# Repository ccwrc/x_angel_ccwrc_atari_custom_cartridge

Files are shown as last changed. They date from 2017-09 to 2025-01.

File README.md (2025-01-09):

PCB look cartridge_pcb

## PCB fit to standard Atari XEGS (Taiwan), Warner and Sikor_Soft cases 

Details, manual, cookbook: [AtariOnline (Polish)](http://atarionline.pl/forum/comments.php?DiscussionID=4245&page=1#Item_0)      
Or auto translated to English: [AtariOnline (English - auto-translated)](https://atarionline-pl.translate.goog/forum/comments.php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)      
The cartridge has been successfully tested with Atari 600XL, 800XL, 65XE, 130XE, 800XE and 65XE with memory expansion.    

## Where to Buy Cases       

Compatible cases are available for purchase through: [Sikor_Soft PL](http://sikorsoft.waw.pl/obudowy-do-cartridge-y/) or [Sikor_Soft Worldwide](http://sikorsoft.waw.pl/en/cartridge-cases/)

Final result atari_xl_xe_cartridge

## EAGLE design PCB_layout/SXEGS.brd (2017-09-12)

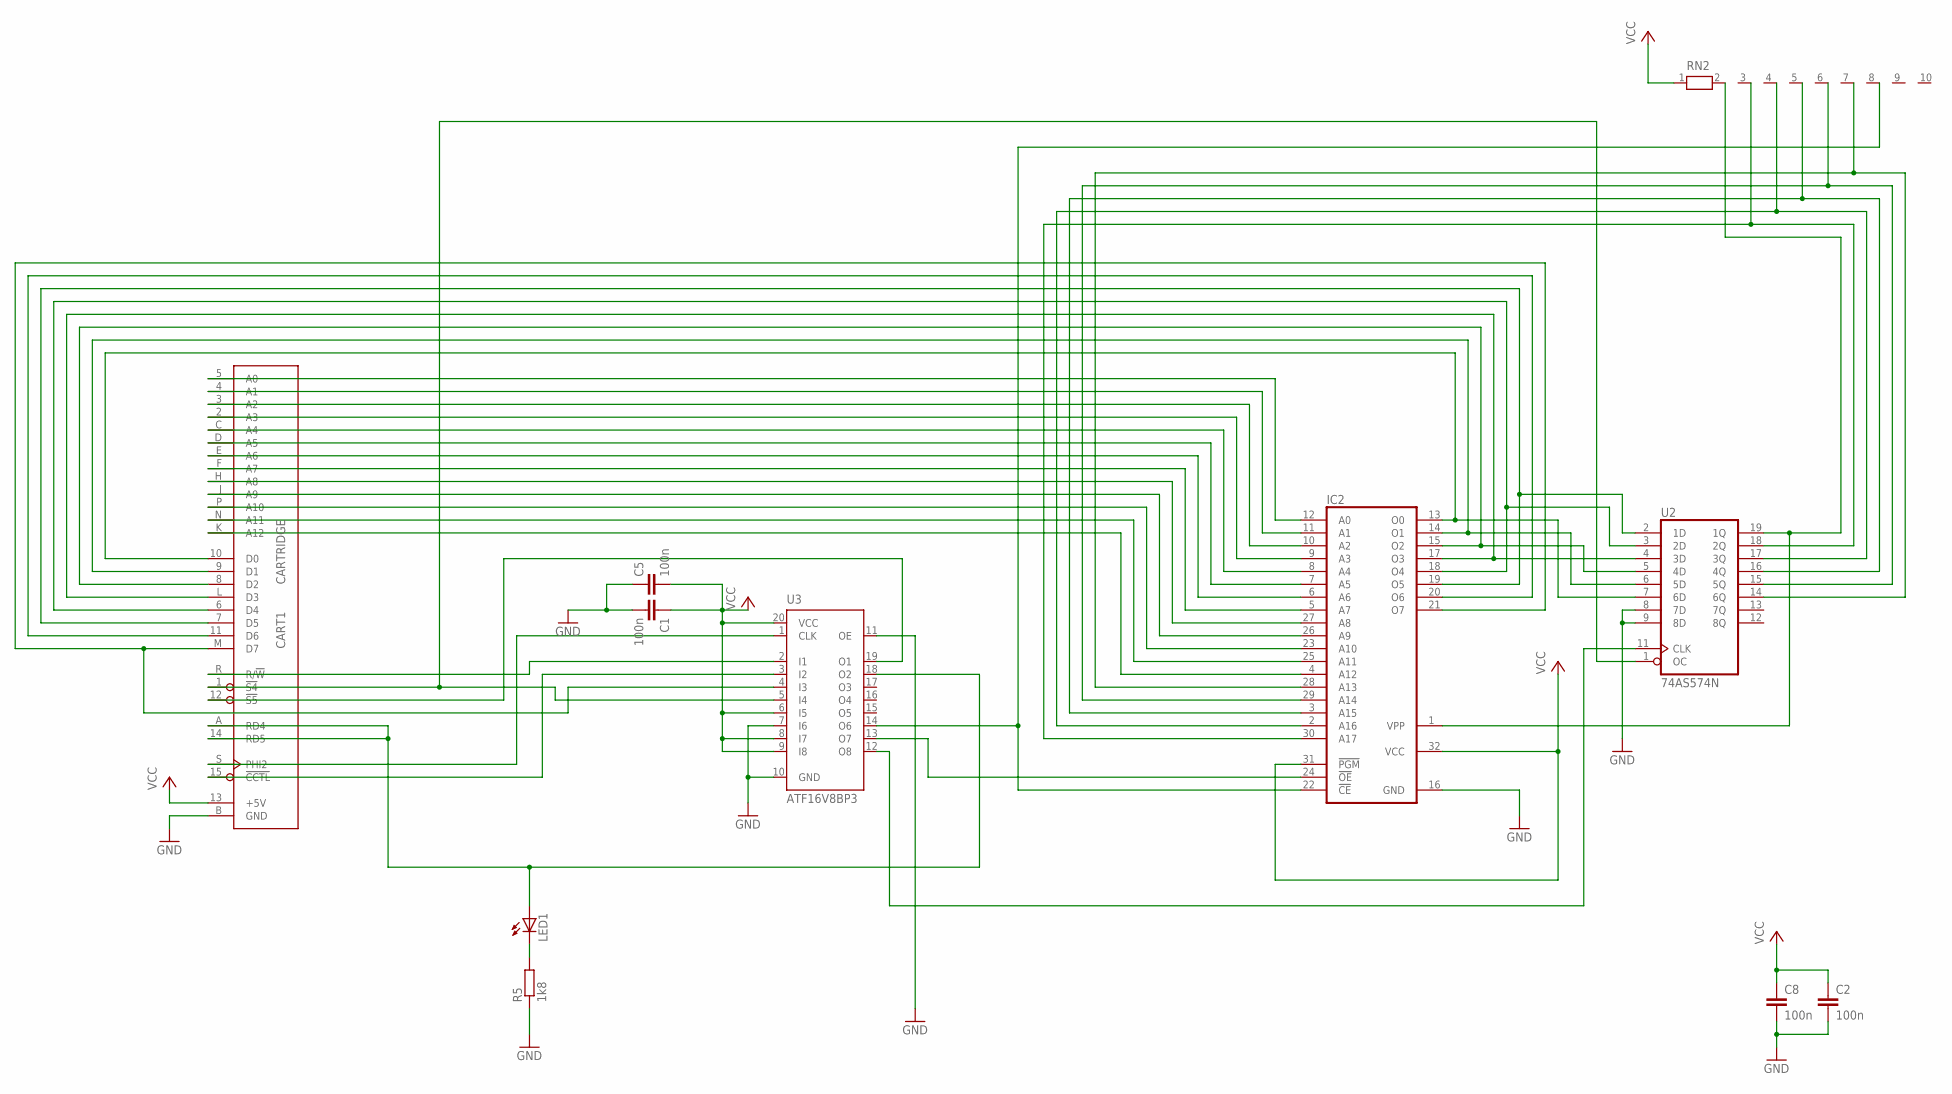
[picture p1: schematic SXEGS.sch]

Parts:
C1: 100n; C050-024X044
C2, C5, C8: 100n; C0805
CART1: CARTRIDGE
IC2: 27C2001D; DIL32
LED1: LEDCHIP-LED0805; CHIP-LED0805
R5: 1k8; R0805
RN2: RN09; RN-10
U2: 74AS574N; DIL20
U3: ATF16V8BP3; DIL20

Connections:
GND: C1.2, C2.2, C5.1, C8.2, CART1.B (GND), IC2.16 (GND), R5.1, U2.8 (7D), U2.9 (8D), U2.10 (GND), U3.7 (I6), U3.10 (GND), U3.11 (OE)
unnamed: LED1.C, R5.2
unnamed: IC2.30 (A17), RN2.3, U2.18 (2Q)
unnamed: CART1.R (R/!W), U3.2 (I1)
unnamed: CART1.14 (RD5), CART1.A (RD4), LED1.A, U3.18 (O2)
unnamed: IC2.1 (VPP), RN2.2, U2.19 (1Q)
unnamed: CART1.15 (!CCTL), U3.3 (I2)
unnamed: CART1.S (PHI2), U3.1 (CLK)
unnamed: CART1.1 (!S4), U2.1 (OC), U3.5 (I4)
unnamed: CART1.12 (!S5), U3.19 (O1)
unnamed: IC2.22 (!CE), RN2.8, U3.14 (O6)
unnamed: IC2.24 (!OE), U3.13 (O7)
unnamed: U2.11 (CLK), U3.12 (O8)
unnamed: CART1.10 (D0), IC2.13 (O0), U2.7 (6D)
unnamed: CART1.9 (D1), IC2.14 (O1), U2.6 (5D)
unnamed: CART1.8 (D2), IC2.15 (O2), U2.5 (4D)
unnamed: CART1.L (D3), IC2.17 (O3), U2.4 (3D)
unnamed: CART1.6 (D4), IC2.18 (O4), U2.3 (2D)
unnamed: CART1.7 (D5), IC2.19 (O5), U2.2 (1D)
unnamed: CART1.11 (D6), IC2.20 (O6)
unnamed: CART1.M (D7), IC2.21 (O7), U3.4 (I3)
unnamed: CART1.5 (A0), IC2.12 (A0)
unnamed: CART1.4 (A1), IC2.11 (A1)
unnamed: CART1.3 (A2), IC2.10 (A2)
unnamed: CART1.2 (A3), IC2.9 (A3)
unnamed: CART1.C (A4), IC2.8 (A4)
unnamed: CART1.D (A5), IC2.7 (A5)
unnamed: CART1.E (A6), IC2.6 (A6)
unnamed: CART1.F (A7), IC2.5 (A7)
unnamed: CART1.H (A8), IC2.27 (A8)
unnamed: CART1.J (A9), IC2.26 (A9)
unnamed: CART1.P (A10), IC2.23 (A10)
unnamed: CART1.N (A11), IC2.25 (A11)
unnamed: CART1.K (A12), IC2.4 (A12)
unnamed: IC2.28 (A13), RN2.7, U2.14 (6Q)
unnamed: IC2.29 (A14), RN2.6, U2.15 (5Q)
unnamed: IC2.3 (A15), RN2.5, U2.16 (4Q)
unnamed: IC2.2 (A16), RN2.4, U2.17 (3Q)
VCC: C1.1, C2.1, C5.2, C8.1, CART1.13 (+5V), IC2.31 (!PGM), IC2.32 (VCC), RN2.1, U2.20 (VCC), U3.6 (I5), U3.8 (I7), U3.9 (I8), U3.20 (VCC)

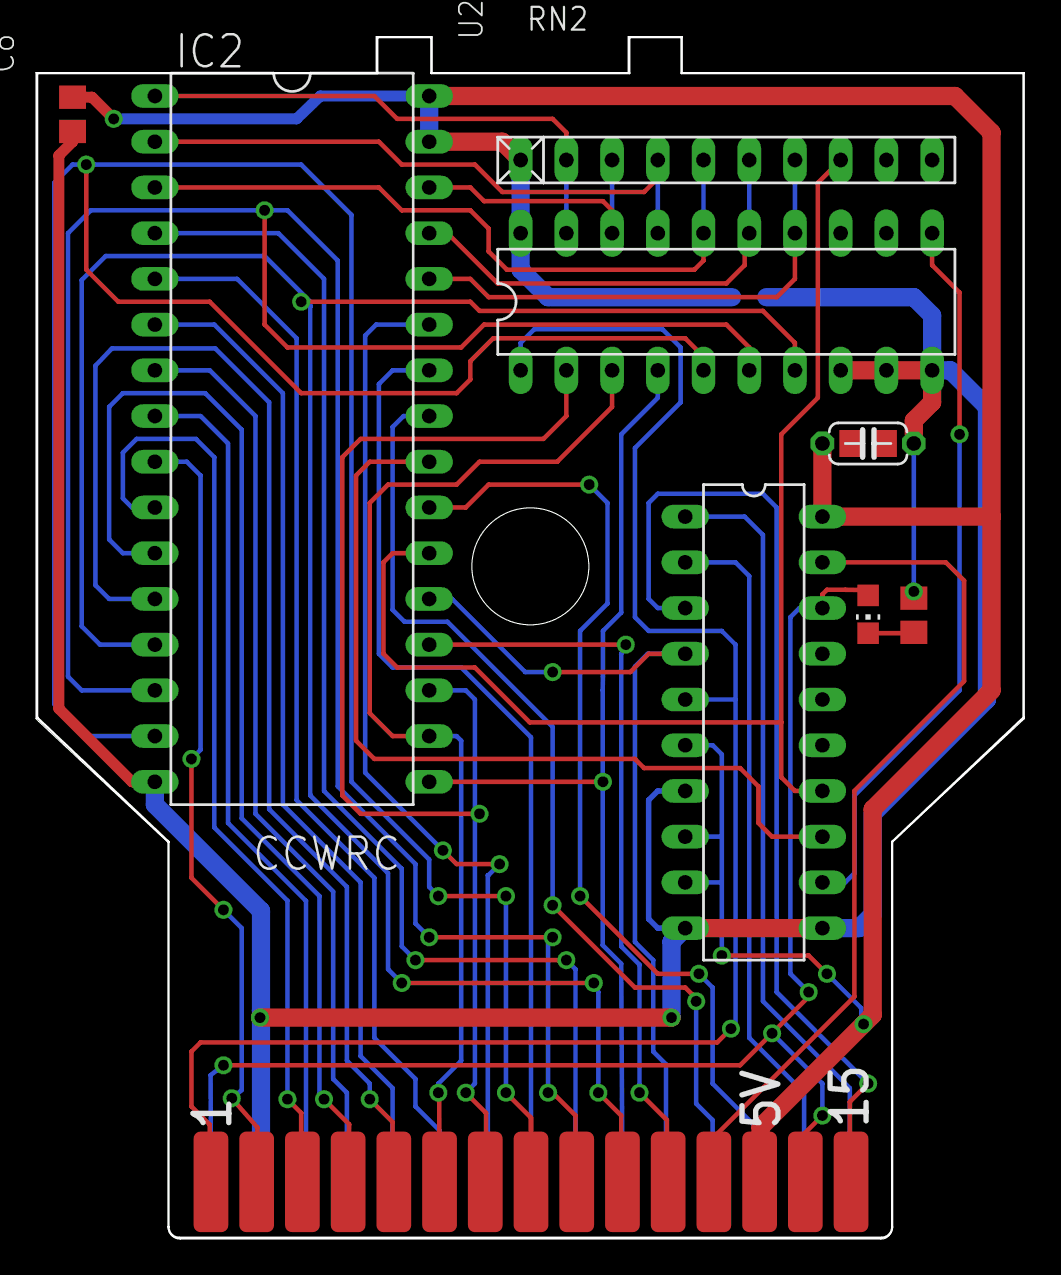
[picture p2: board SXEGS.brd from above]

Board: 2 copper layers, 54.9 x 66.8 mm, 11 parts (1 on the bottom side), 39 nets.

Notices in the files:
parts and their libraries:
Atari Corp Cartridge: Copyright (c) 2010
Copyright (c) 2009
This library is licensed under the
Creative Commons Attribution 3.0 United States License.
